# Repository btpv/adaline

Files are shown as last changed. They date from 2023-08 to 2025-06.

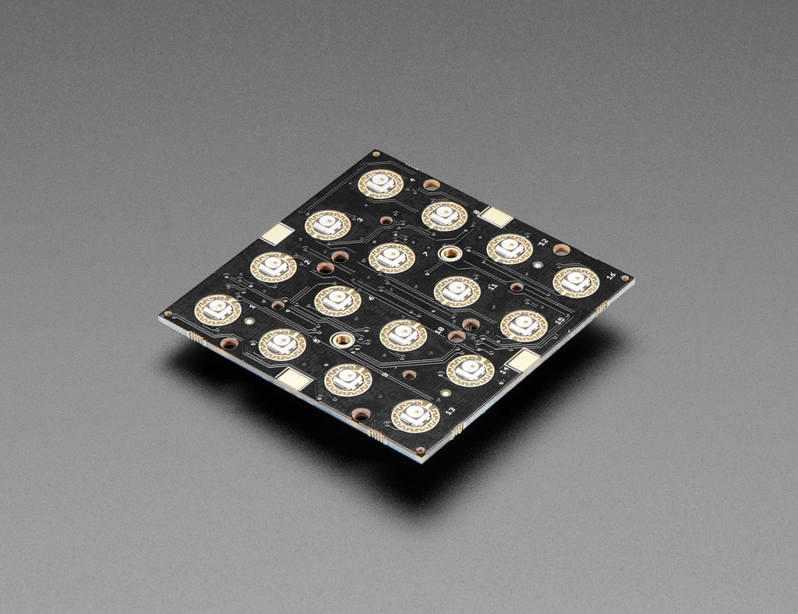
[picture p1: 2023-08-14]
Neo_Trellis.jpg

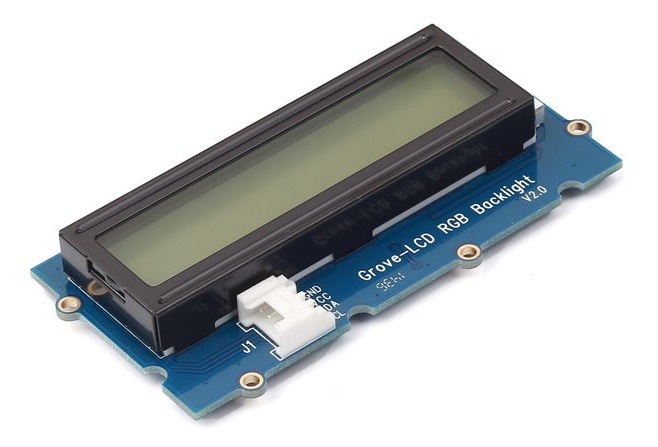
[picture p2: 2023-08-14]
RGB_LCD.jpg

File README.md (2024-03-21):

# adaline
This repository is a complete design instruction to enable users to recreate the Widrow-Hoff Adaline demonstrator (as originally conceived by Bernard Widrow and Ted Hoff) in 1960.
The design is modernised using digital peripherals and an Arduino Uno microcontroller to make the design as inexpensive as possible (total cost is approximately $62)
The aim of the project is to encourage educators to build their own devices to help explore the concept of the Least Mean Square algorithm and disseminate the concepts more widely
perhaps among Schools and Colleges.

Here is a video demonstrating how to train the device: https://youtu.be/jZf1iUhlR3M

Here is a link to a video (from 2012) which inspired this project.  It features none other than Prof Bernard Widrow himself demonstrating his Adaline device: https://youtu.be/hc2Zj55j1zU and Part 2: https://youtu.be/skfNlwEbqck

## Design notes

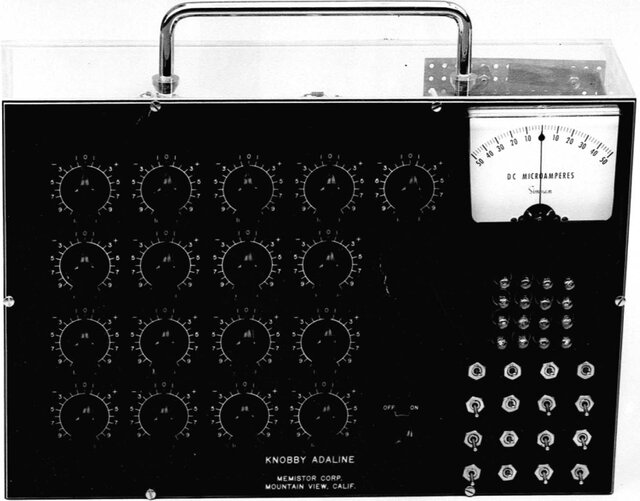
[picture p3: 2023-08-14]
Knobby-ADALINE.jpg

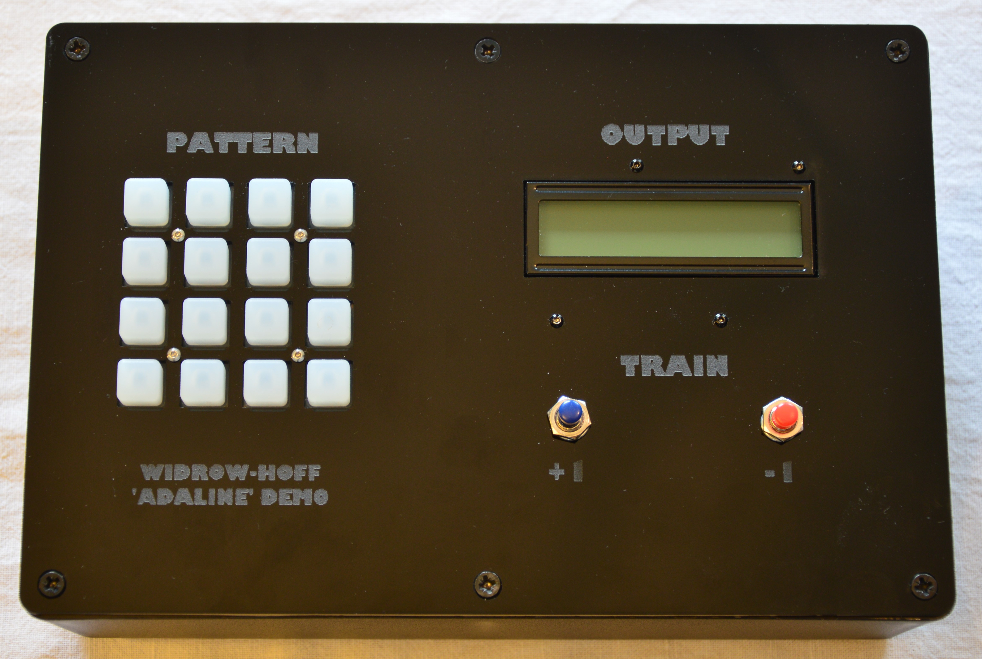
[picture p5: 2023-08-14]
Front_View_Adaline.JPG

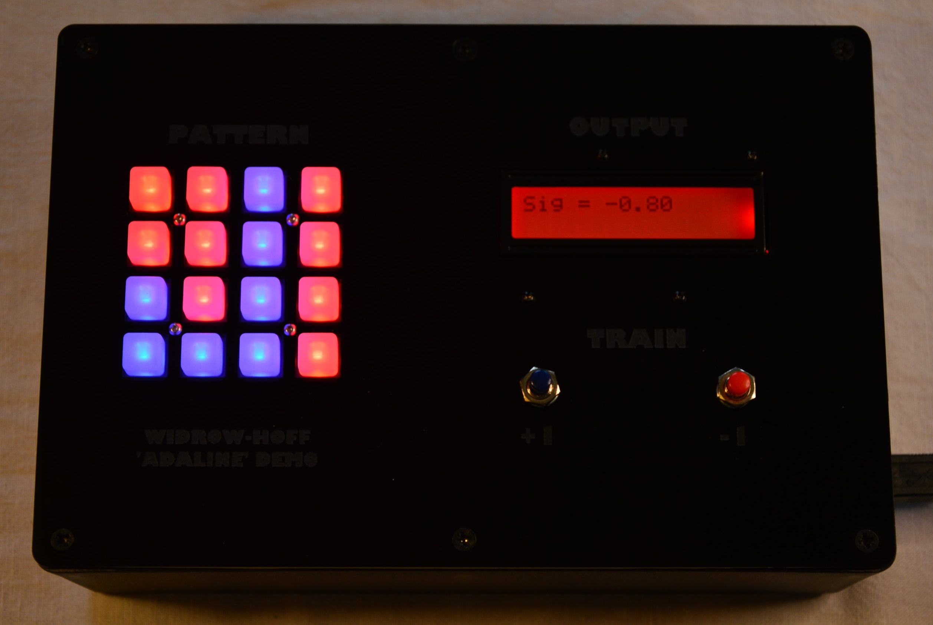
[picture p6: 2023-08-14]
J_Pattern2.jpg

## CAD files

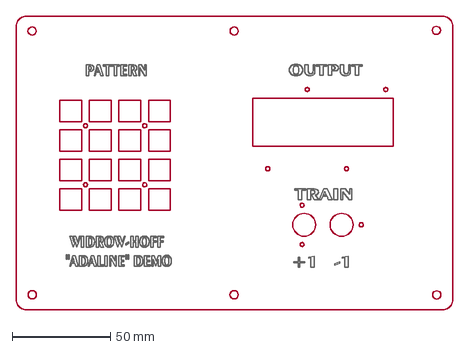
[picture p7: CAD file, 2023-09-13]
Adaline Top panel.dxf
221.5 x 149.0 mm

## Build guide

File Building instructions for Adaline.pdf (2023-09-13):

## Widrow-Hoff ‘Adaline’ Demonstrator Design Instructions

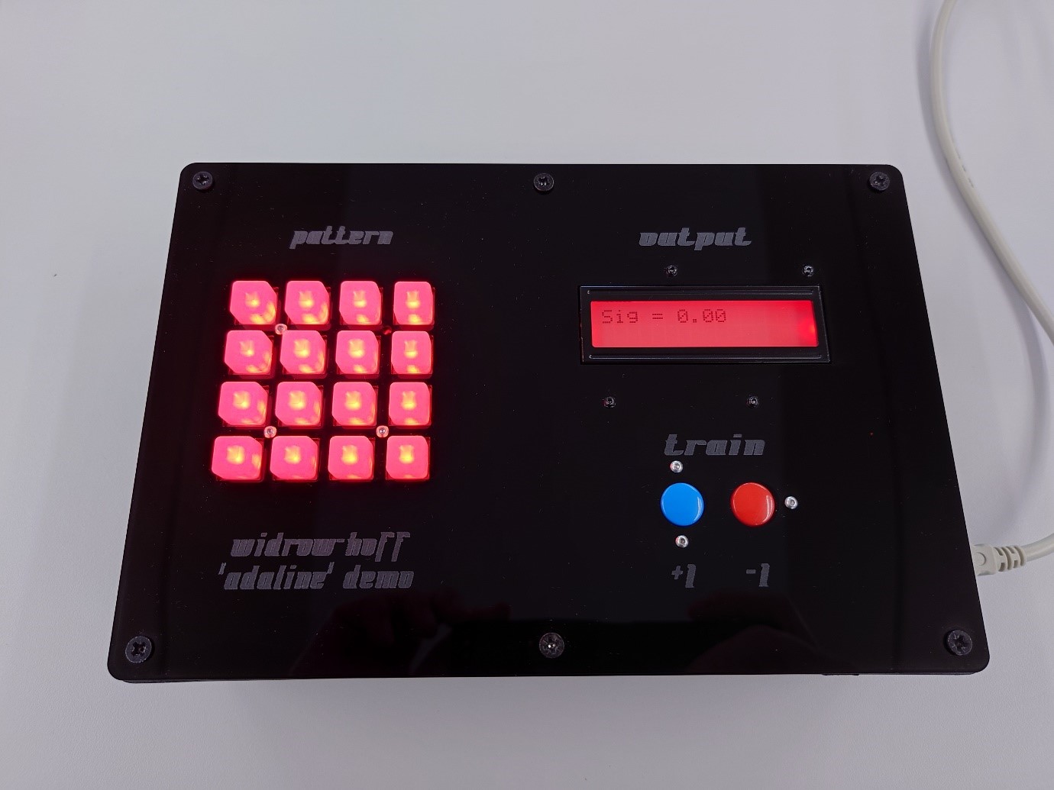
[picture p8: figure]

This document is a complete set of design instructions to enable users to recreate the Widrow-Hoff ‘Adaline’ demonstrator device (as originally conceived by Bernard Widrow and Ted Hoff) in 1960.

The design is modernised using digital peripherals and an Arduino Uno microcontroller to make the design as inexpensive as possible (total cost is approximately $62) The aim of the project is to encourage educators to build their own devices to help explore the concept of the Least Mean Square algorithm and disseminate the concepts more widely perhaps among Schools and Colleges.

Here is a video demonstrating how to train the device once it has been constructed: https://youtu.be/PBz0Q8OuVuk

Here is a link to a video (from 2012) which inspired this project. It features Prof Bernard Widrow himself demonstrating his Adaline device Part 1: https://youtu.be/hc2Zj55j1zU and Part 2: https://youtu.be/skfNlwEbqck

Tools:

- Laser cutting machine (preferred but not essential)
- Hand drill
- Drill bits
- Small Philips screwdriver
- Small flat blade screwdriver
- Snipe nose pliers
- Blade
- Small file
- Safety glasses

Components:

- ABS Enclosure
https://www.ebay.co.uk/itm/195228858248?hash=item2d748bf788:g:twkAAOSwRGBZd5t3
- Acrylic Perspex sheet 3mm thick (.dxf design file download for top panel laser cutting)
- Arduino Uno (or clone equivalent)
- Seeed Studio Base Shield v2.1
- Grove - LCD RGB Backlight v4.0
- Grove - Dual Button v1.0
- Adafruit Neo Trellis 4x4
- 4x M2x10mm machine screw
- 4x M2x12mm machine screw
- 4x M2x16mm machine screw
- 4x M2x6mm spacer
- 3x M2x8mm spacer
- 11x M2 nut
- 4x M2 fibre/nylon washer
- 1x Momentary push button (panel mount)
- 4x M3x6mm nylon stand-off
- 4x M3 nylon nut
- 4x M3x10mm slotted screw

Build Instruction:

Begin by using the downloaded .dxf file to cut/engrave the top panel with laser cutting machine. The top panel dimensions are 226x148mm and we are using 3mm thick Perspex/Acrylic. If there is no access to a laser cutter, other materials may be used, such as wood, aluminium, or soft type acrylic (non-shatter) sheet. A hand drill and files may be used to cut and shape all the holes.

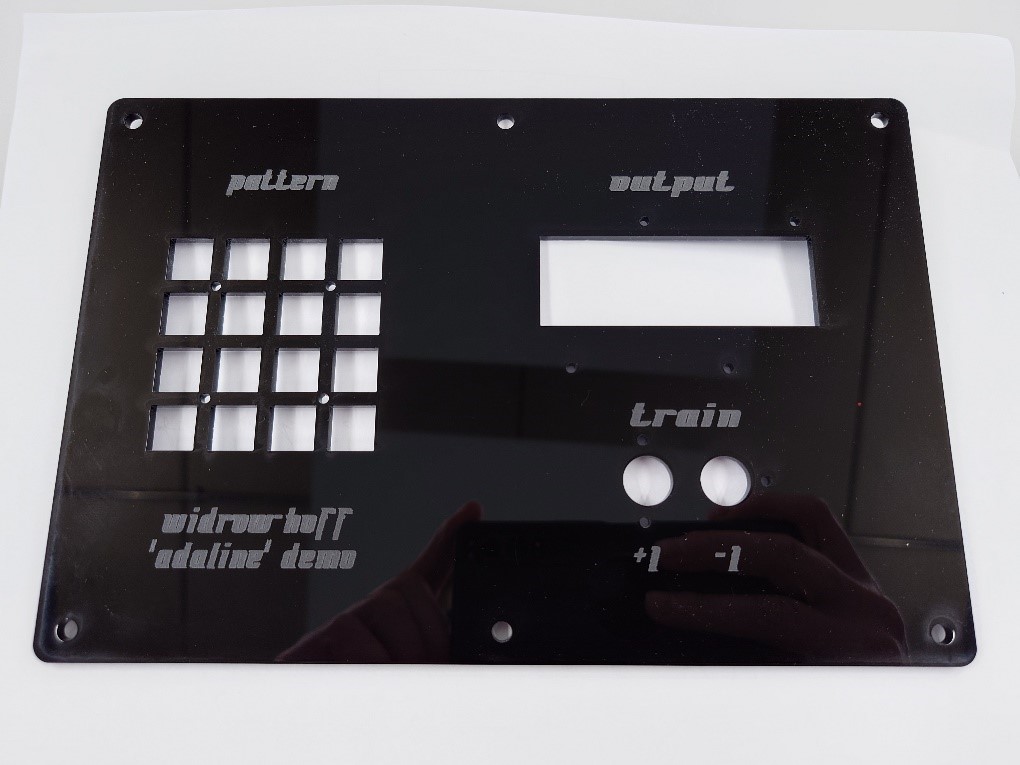
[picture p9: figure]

Next, we can populate the top panel with the Grove LCD RGB backlight, Adafruit Neo Trellis 4x4 Button matrix and the Grove Dual Button components shown below.

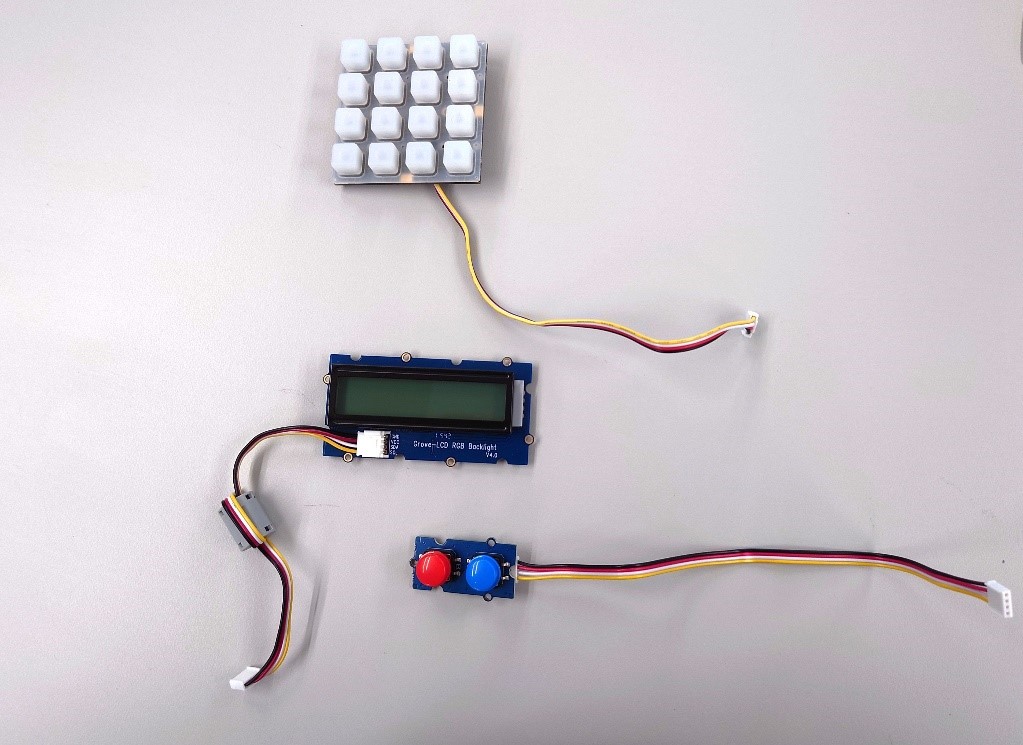
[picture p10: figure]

Using the M2x12mm machine screws, M2x6mm Spacers and M2 nuts (4 of each in total) mount the Grove LCD display into the panel.

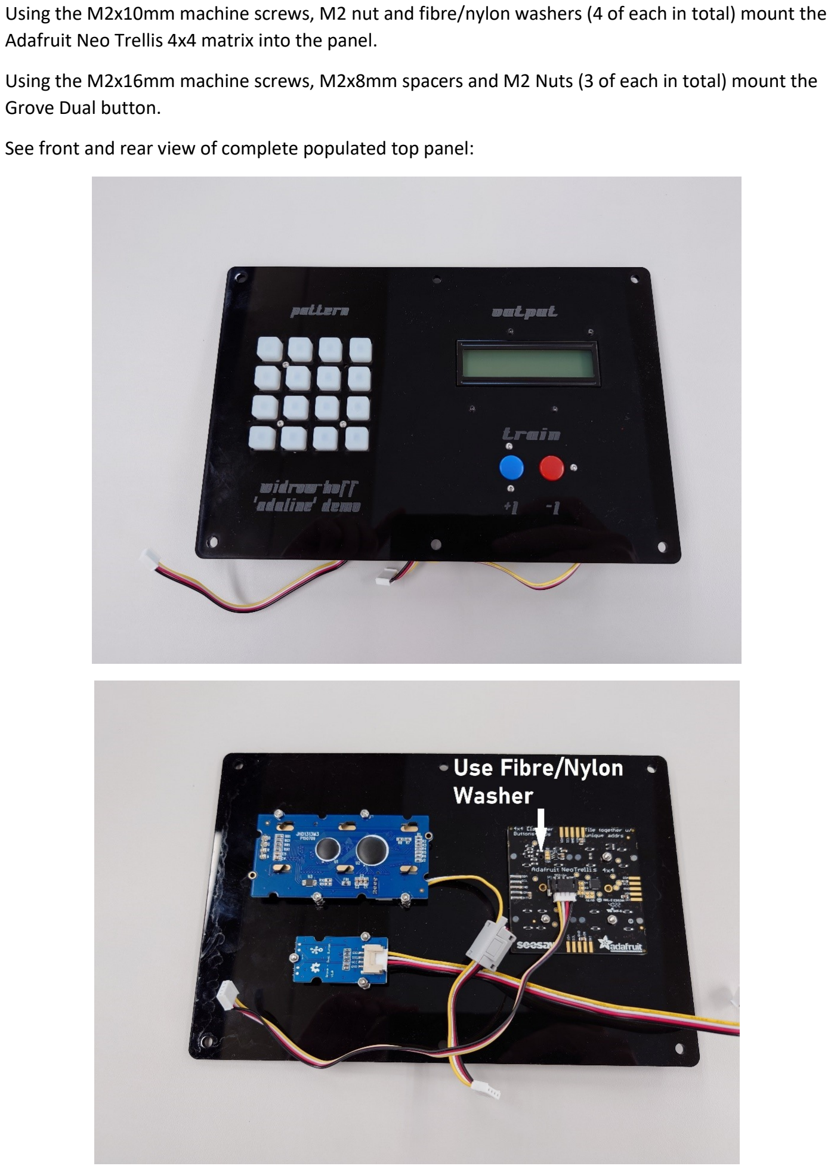
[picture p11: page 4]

Using the M2x10mm machine screws, M2 nut and fibre/nylon washers (4 of each in total) mount the Adafruit Neo Trellis 4x4 matrix into the panel.

Using the M2x16mm machine screws, M2x8mm spacers and M2 Nuts (3 of each in total) mount the Grove Dual button.

See front and rear view of complete populated top panel:

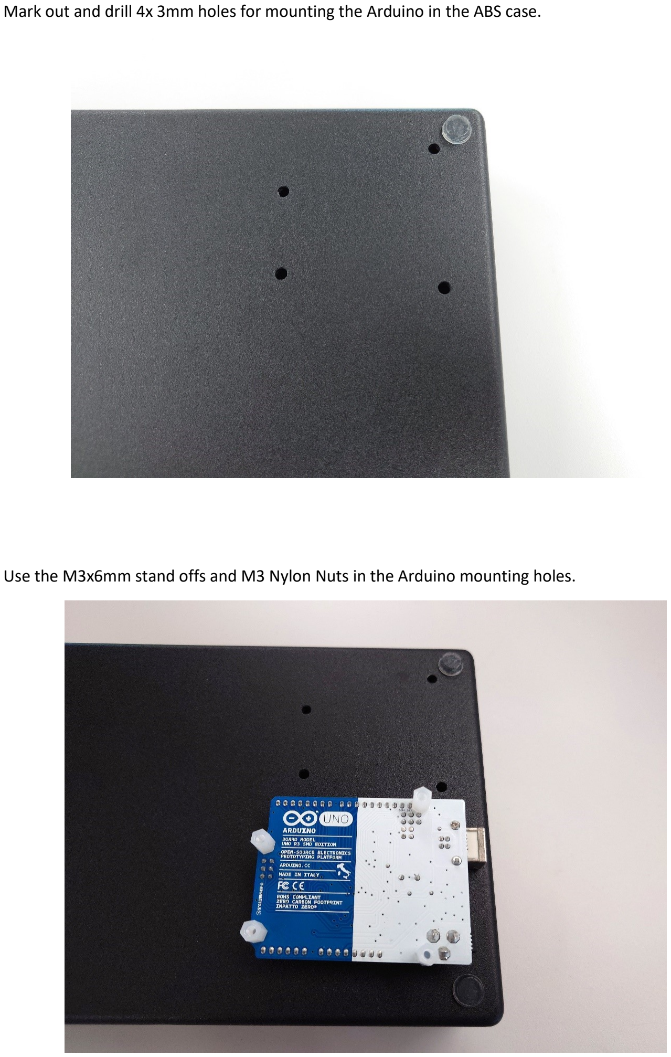
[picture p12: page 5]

Mark out and drill 4x 3mm holes for mounting the Arduino in the ABS case.

Use the M3x6mm stand offs and M3 Nylon Nuts in the Arduino mounting holes.

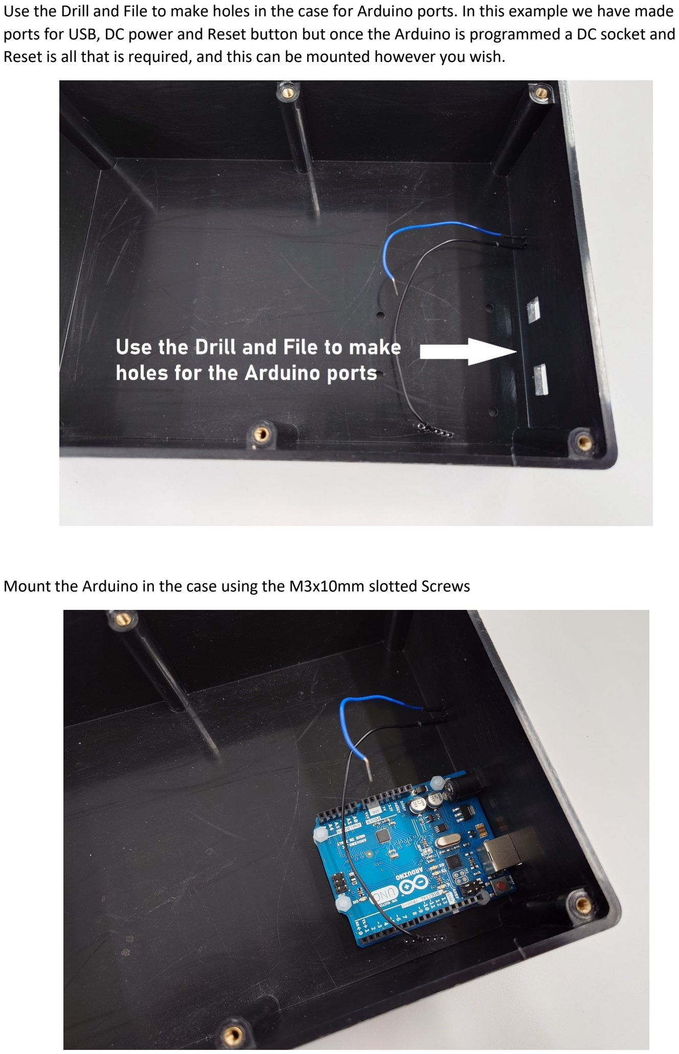
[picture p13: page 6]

Use the Drill and File to make holes in the case for Arduino ports. In this example we have made ports for USB, DC power and Reset button but once the Arduino is programmed a DC socket and Reset is all that is required, and this can be mounted however you wish.

Mount the Arduino in the case using the M3x10mm slotted Screws

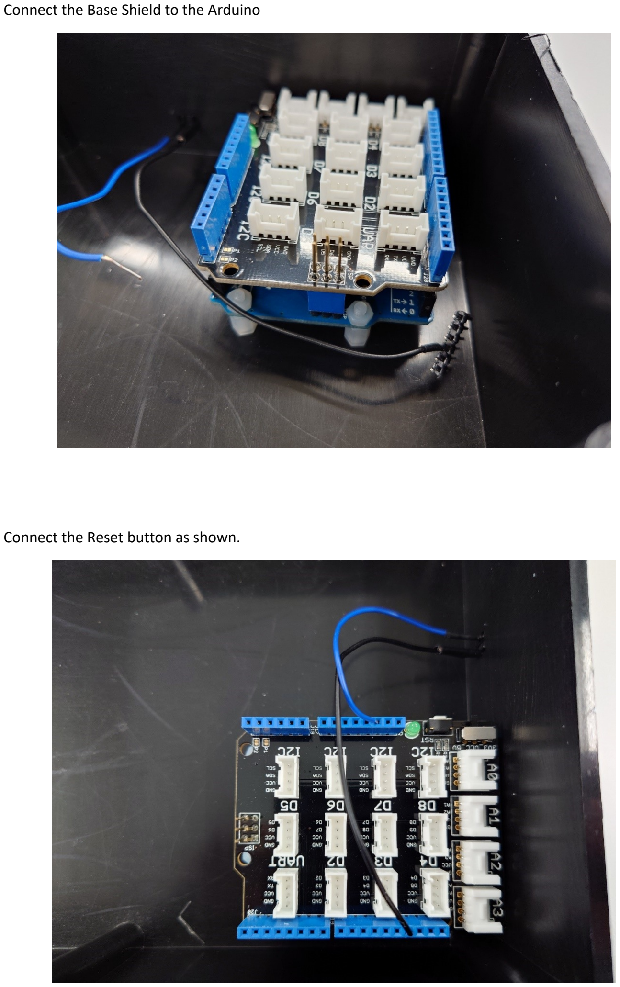
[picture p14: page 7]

Connect the Base Shield to the Arduino

Connect the Reset button as shown.

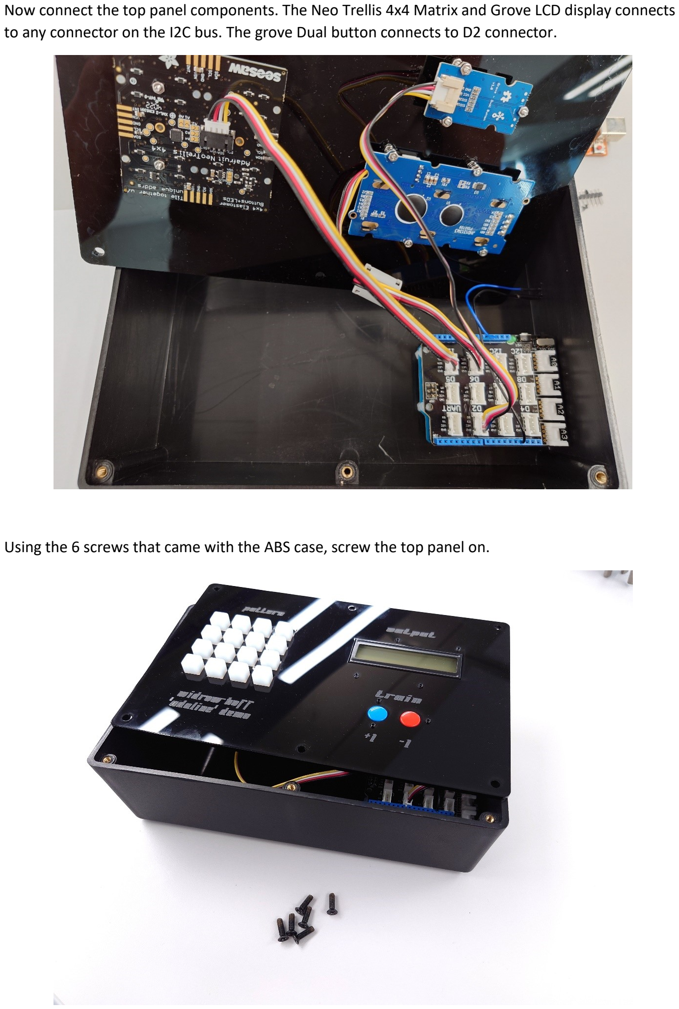
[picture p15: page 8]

Now connect the top panel components. The Neo Trellis 4x4 Matrix and Grove LCD display connects to any connector on the I2C bus. The grove Dual button connects to D2 connector.

Using the 6 screws that came with the ABS case, screw the top panel on.

Download the .ino code and program the Arduino Uno. Finally, power up the unit by your chosen method (we are using the USB port)

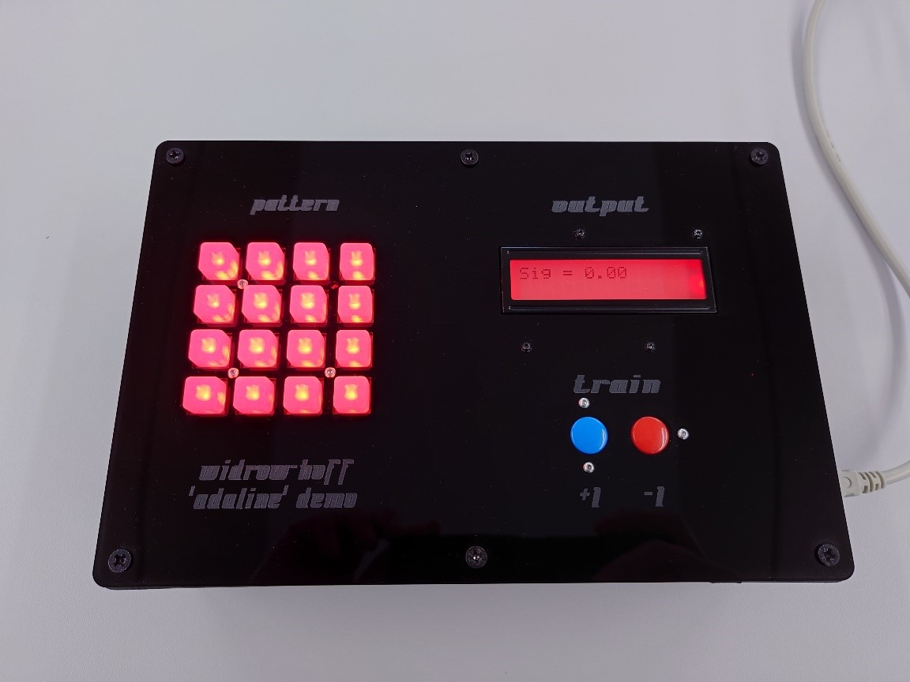
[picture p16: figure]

Now please refer to the document on how to train your Adaline here. (https://github.com/cliveee/adaline/blob/main/How%20to%20train%20your%20Adaline.pdf)

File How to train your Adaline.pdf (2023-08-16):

## How to train your “Adaline”!

### Setting up

Once you have assembled your Widrow-Hoff ‘Adeline’ demonstrator device, you will need to upload the Arduino code from the Github repository here using the Arduino IDE. Connect your computer to the Arduino USB port with the appropriate cable and compile and upload the code to the correct COM port. Once, the upload process is complete, all the keys on the keypad should illuminate completely red and the LCD screen should read, “Sig = –0.00” and have a red background.

### Training

Now select a training pattern, for example a ‘J’ shaped letter perhaps (see Figure 1, this is the example that Bernard Widrow used himself to demonstrate his device back in the 1960s), by pressing the appropriate keys to toggle them to blue as shown below. [One could, of course, choose any pattern (or indeed make a ‘J’ from red buttons on a blue background for example)].

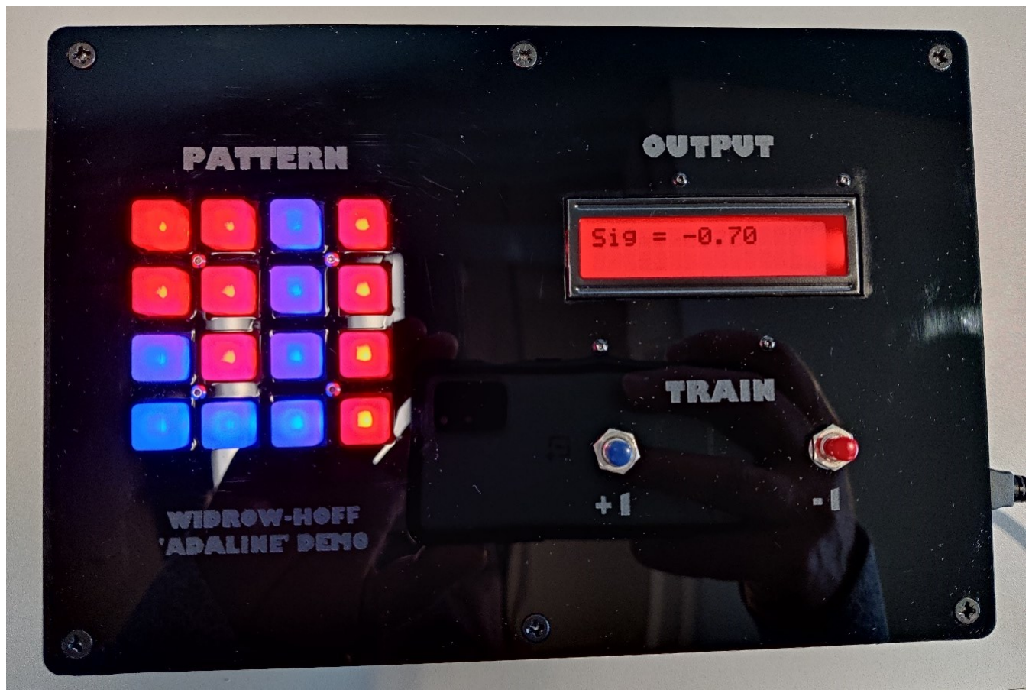
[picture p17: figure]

Figure 1: Enter a ‘J’ pattern using blue buttons on red background and then train by pressing “–1”.

Now that the ‘J’ pattern has been entered, press the red pushbutton (negative class) for a second or so until the Sig value starts to approach –0.7 or lower. It is worth noting that the output value passes through a sigmoid function (hyperbolic tangent, see Figure 2) which is often used in machine learning to normalise the output range from +1 to –1 regardless of its input range. This is helpful if further layers of ‘Adalines’ are used (e.g., in a multi-layer neural network), it also standardises the output range, so we know what to expect. Any absolute value above 0.6 is sufficiently high to show a strong classification effect.

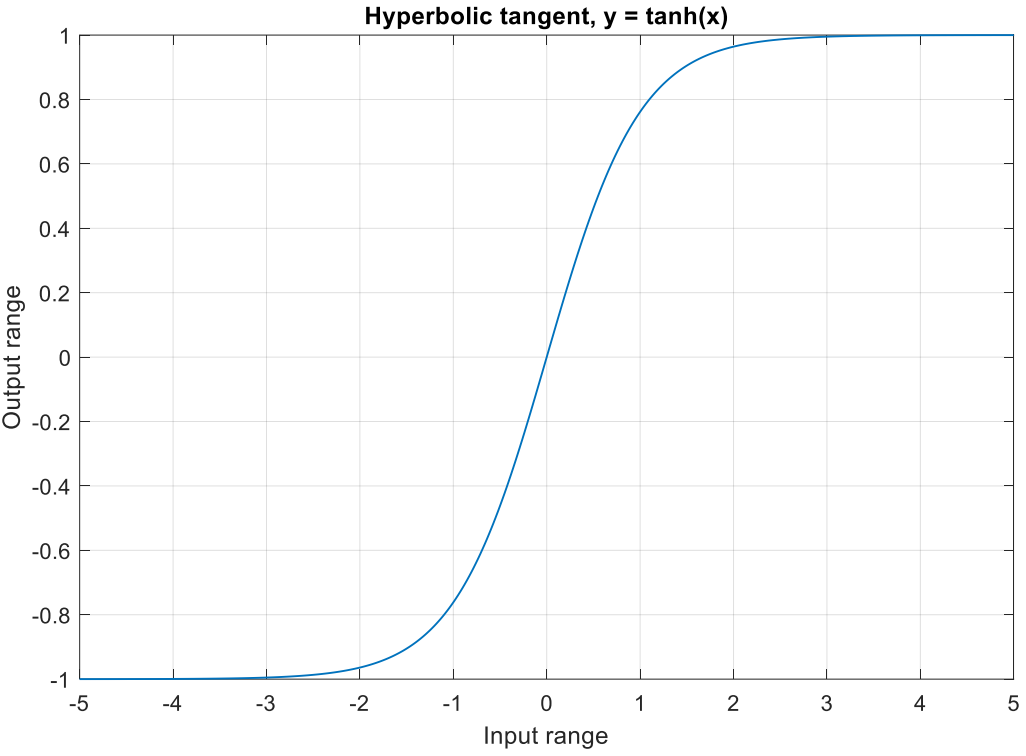
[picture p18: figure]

Figure 2: Hyperbolic tangent [y = tanh(x)] function compresses wide input ranges to ±1 outputs.

Now enter a ‘T’ pattern into the keypad by toggling the relevant buttons to show a ‘T’ like letter as shown below in Figure 3. Then press the blue pushbutton to train this pattern towards the positive class – again a value of Sig = 0.7 or higher is good. Holding the button for a second or two should be enough to achieve this.

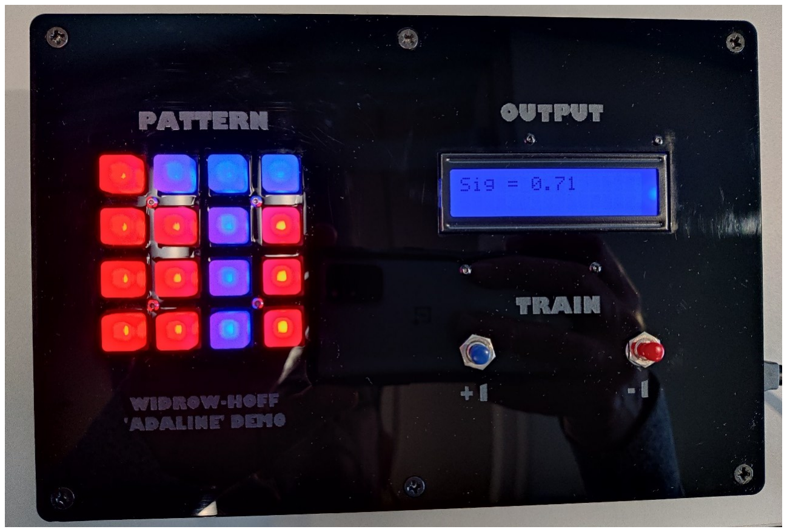
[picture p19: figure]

Figure 3: Enter a ‘T’ pattern using blue buttons on red background and then train by pressing “+1”.

Since pressing either button invokes the LMS algorithm and adapts the internal weight vector, it is likely that the previous ‘J’ pattern output may have been affected (as they share several common ‘input’ buttons in their respective patterns). So, change the pattern back to the original ‘J’ shape by toggling the buttons once more to check. If the Sig output is not sufficiently negative, then press the red pushbutton once again to re-train the machine to achieve a negative output approaching –0.8 or thereabouts. It may also be a good idea to recheck the ‘T’ pattern – after a couple of checks back forth – the system should have correctly classified the two letter patterns correctly, i.e., the ‘J’ belonging to the negative (red) class and the ‘T’ to the positive (blue) class.

### Translated Patterns

One can extend the patterns that the machine can recognise perhaps by translating the original patterns by one ‘pixel’ (again Widrow used this idea himself in his original Adaline machine). By this we mean to input the same ‘J’ and ‘T’ patterns but shifted horizontally by one column of keys to the right or left.

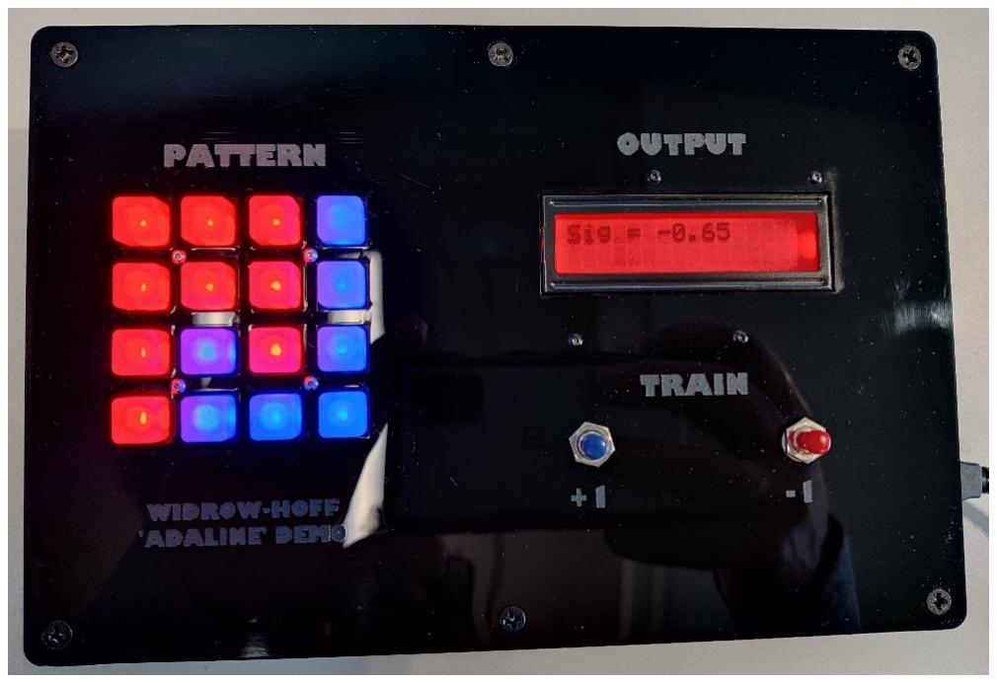
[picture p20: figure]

Figure 4: Enter a translated ‘J’ pattern and then train by pressing “–1”.

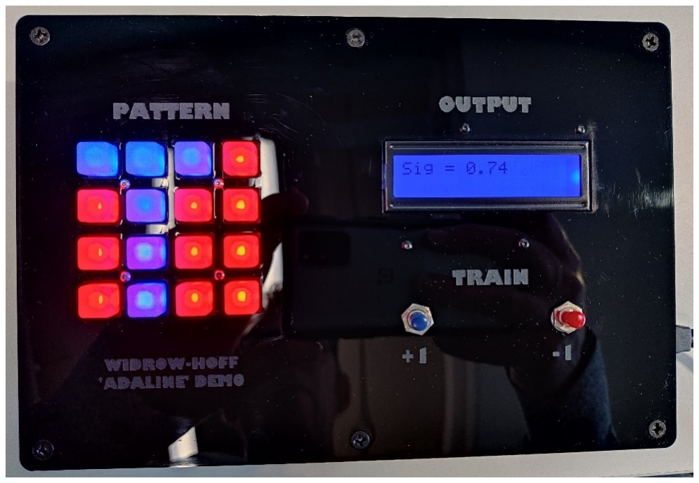
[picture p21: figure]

Figure 5: Enter a translated ‘T’ pattern and then train by pressing “+1”.

So, we could train the device to classify the translated ‘J’ also as the negative (red) class and the translated ‘T’ as the positive (blue) class. In doing so, we should check the original patterns once again and, through an iterative process of checking and retraining (if needed), it should be easily possible to match both ‘J’s to the -ve class (red) and both ‘T’s to the positive class (blue).

One could extend this experiment further – it should be possible to introduce rotated letters on the keypad and group them in the correct classes. So long as the patterns differ by at least one ‘pixel’ or button, then the machine can learn to distinguish them through sufficient training.

The authors would encourage users to experiment as much as they can with the device to get maximum understanding of the Adaline and LMS algorithms. Indeed, it would be interesting to receive any suggestions to improve or ameliorate the device in the future. Please feel free to contribute your own designs to the project.

V1.0

This work is licensed under a Creative Commons Attribution-ShareAlike 4.0 International License. (http://creativecommons.org/licenses/by-sa/4.0/)

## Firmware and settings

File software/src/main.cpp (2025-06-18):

//include the libraries
#include <Wire.h>
#include <Arduino.h>
#include <rgb_lcd.h>
#include <Adafruit_NeoTrellis.h>
#include <U8x8lib.h>

#define BTNP 2
#define BTNN 3

//define the class instances
U8X8_SSD1306_128X64_NONAME_HW_I2C display(-1);
rgb_lcd lcd;
Adafruit_NeoTrellis trellis;


double I[17] = { -1,-1,-1,-1,
             -1,-1,-1,-1,
             -1,-1,-1,-1,
             -1,-1,-1,-1, 1 };
double weights[17];
double mu = 0.002;

//define the functions used in the program
TrellisCallback btnPress(keyEvent evt); //trellis callback function
double output();                        //calculate the output of the algorithm   
void scanI2C();                         //scan the i2c bus for devices
void setLed(uint16_t i);                //set the color of a button
void update(double out, double des);    //calculate the error and update the weights
void printLcd(double out);              //update the lcd display
void printOled();                       //update the oled display
void reset();                           //reset the weights back to 0
void menu();                            //open up the menu
int getDecimalDigit(double num,int d);   //get the third decimal digit of a number
void setup() {
  Serial.begin(9600);
  scanI2C();
  pinMode(2, INPUT_PULLUP);
  pinMode(3, INPUT_PULLUP);
  //initialize the oled display
  if (!display.begin()) {
    Serial.println("SSD1306 fialed to initialize");
    for (;;);
  } else {
    Serial.println("SSD1306 initialized");
  }
  display.setFont(u8x8_font_chroma48medium8_r); //select a font
  display.clear();                              //clear the display
  display.display();                            //display the cleared display

  //initialize the lcd display
  lcd.begin(16, 2);
  Serial.println("LCD initialized");

  //initialize the trellis
  if (!trellis.begin(0x2E)) {
    Serial.println("Could not start trellis, check wiring?");
    for (;;);
  } else {
    Serial.println("NeoPixel Trellis started");
  }

  for (int i = 0; i < NEO_TRELLIS_NUM_KEYS; i++) {
    trellis.activateKey(i, SEESAW_KEYPAD_EDGE_RISING); //set the callback function to rising edges
    trellis.registerCallback(i, btnPress);             //register the callback function
    setLed(i);                                         //set the initial color
  }
  delay(1000);
}


void loop() {
  // read the trellis and let it handle the callback
  trellis.read();

  double out = output();// calculate the output of the algorithm

  // handle the button inputs
  
  printLcd(out); // update the lcd
  if (!digitalRead(BTNP)&&!digitalRead(BTNN)) {
    menu();
  }
  if (digitalRead(BTNP) == false) {

    update(out, 1); //calculate the error and update the weights
  }
  if (digitalRead(BTNN) == false) {
    update(out, -1); //calculate the error and update the weights
  }
  printOled();   // update the oled display
  delay(50);
}

void setLed(uint16_t i) {
  // set the pixel color to red or blue depending on the state of the button
  trellis.pixels.setPixelColor(i, I[i] == 1 ? 0x000015 : 0x150000);
  trellis.pixels.show(); //push the changes to the trellis
}

//callback function for the trellis that is called when a button state changes
TrellisCallback btnPress(keyEvent evt) {
  if (evt.bit.EDGE != SEESAW_KEYPAD_EDGE_RISING) return 0; // ignore key releases 
  I[evt.bit.NUM] *= -1; // invert the value of the key
  setLed(evt.bit.NUM); //update the button color
  delay(5); //and wait a bit to debounce
  return 0;
}

double output() {
  double out = 0;
  // calculate the output
  for (int i = 0; i < NEO_TRELLIS_NUM_KEYS + 1; i++) {
    out = out + weights[i] * I[i];
  }
  return out;
}

void update(double out, double des) {
  // calculate the error
  double err = des - out;
  // update the weights
  for (int i = 0; i < NEO_TRELLIS_NUM_KEYS + 1; i++) {
    weights[i] = weights[i] + 2 * mu * err * I[i];
  }
}

// scan the i2c bus for devices
void scanI2C() {
  Wire.begin();
  //loop trough all the i2c addresses
  for (uint8_t i = 1; i < 127; i++) {
    // send a ping to the device
    Wire.beginTransmission(i);
    // if the device responds, print its address
    if (Wire.endTransmission() == 0) {
      Serial.print("0x");
      Serial.print(i, HEX);
      Serial.println(" ");
    }
  }
}

int getDecimalDigit(double num,int d) {
  num = fabs(num); // make sure it's positive
  num *= pow(10,d+1);     // move d digits after decimal to before decimal
  int temp = static_cast<int>(num); // truncate to int
  return temp % 10; // get the last digit
}
void printLcd(double out) {
  double sig = tanh(2 * out);
  lcd.setCursor(0, 0); //set the cursor to the top left corner
  //print the output to the lcd
  lcd.print("Sig = ");
  lcd.print(sig);
  lcd.print("  ");

  //set the color of the lcd display depending on the output
  int brightness = pow(abs(sig), 4) * 245 + 10;
  if (sig < 0) {
    lcd.setRGB(brightness, 0, 0); //red if sig is negative
  } else if (sig > 0) {
    lcd.setRGB(0, 0, brightness);  //blue if sig is positive
  } else {
    lcd.setRGB(0, 255, 0);        //green otherwise
  }
}
void printOled() {
  for (int x = 0; x < 4; x++) {
    for (int y = 0; y < 4; y++) {
      char buffer[6]; // create a buffer for the string we want to print to the display
      sprintf(buffer, "%4d", (int)(weights[x * 4 + y] * 100)); // format the number to a string
      display.drawString(x * 4, y * 2, buffer); // print the string to the display
    }
  }
}
void menu() {
  lcd.clear();
  lcd.setCursor(0, 0);
  lcd.print("Adaline Menu");
  int i = 0;
  const char* menuItems[] = { "Reset", "Change mu", "Exit" };
  while (!digitalRead(BTNN) || !digitalRead(BTNP)); //wait for buttons to be released
  while (true) {
    lcd.setCursor(0, 1);
    // add 16 spaces after the string and remove everything after the 16th character to make sure that the line is cleared of previous text
    lcd.print((String(menuItems[i]) + "                ").substring(0, 16));
    while (digitalRead(BTNN) && digitalRead(BTNP)); //wait for button press
    delay(50); //wait for a possible second button press
    Serial.println(i);
    if (!digitalRead(BTNN) && !digitalRead(BTNP)) {
      if (i == 0) {
        reset();
      }
      if (i == 1) {
        // mu = getNumber();
        double newMu = mu;
        double d = 0;
        int l = 1;
        
        while (true) {
          lcd.print((String(newMu) + "                ").substring(0, 16));
          if (!digitalRead(BTNP)) {
            d++;
            if (d > 9) { d = 0; }
            delay(50); //debounce
            while (digitalRead(BTNP)); //wait for button release
            delay(50); //debounce
          } else if (!digitalRead(BTNN)) {
            d--;
            if (d < 0) { d = 9; }
            delay(50); //debounce
            while (digitalRead(BTNN)); //wait for button release
            delay(50); //debounce
          }
        }
      }
      if (i == 2) {
      }
      break;
    } else if (!digitalRead(BTNP)) {
      i++;
      if (i >= sizeof(menuItems) / sizeof(menuItems[0])) { i = 0; } //wrap around
      delay(50); //debounce
      while (digitalRead(BTNP)); //wait for button release
      delay(50); //debounce
    } else if (!digitalRead(BTNN)) {
      i--;
      if (i < 0) { i = sizeof(menuItems) / sizeof(menuItems[0])-1; } //wrap around
      delay(50); //debounce
      while (digitalRead(BTNN)); //wait for button release
      delay(50); //debounce
    }
  }
  lcd.clear();
}
void reset() {
  for (int i = 0; i < 17; i++) {
    weights[i] = 0;
    I[i] = 0;
  }
}

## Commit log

2023-08-11 Main Arduino Uno file for Adaline Demonstrator
2023-08-14 Adaline Arduino Uno code
2023-08-15 DXF file for top panel of Adaline
    File used to cut and etch the black acrylic top panel of our Adaline demonstrator
    [Adaline_Box_Lid.dxf]
2023-08-16 Main Arduino Uno Code
2023-09-13 Top panel laser cutter file
    [Adaline Top panel.dxf]
